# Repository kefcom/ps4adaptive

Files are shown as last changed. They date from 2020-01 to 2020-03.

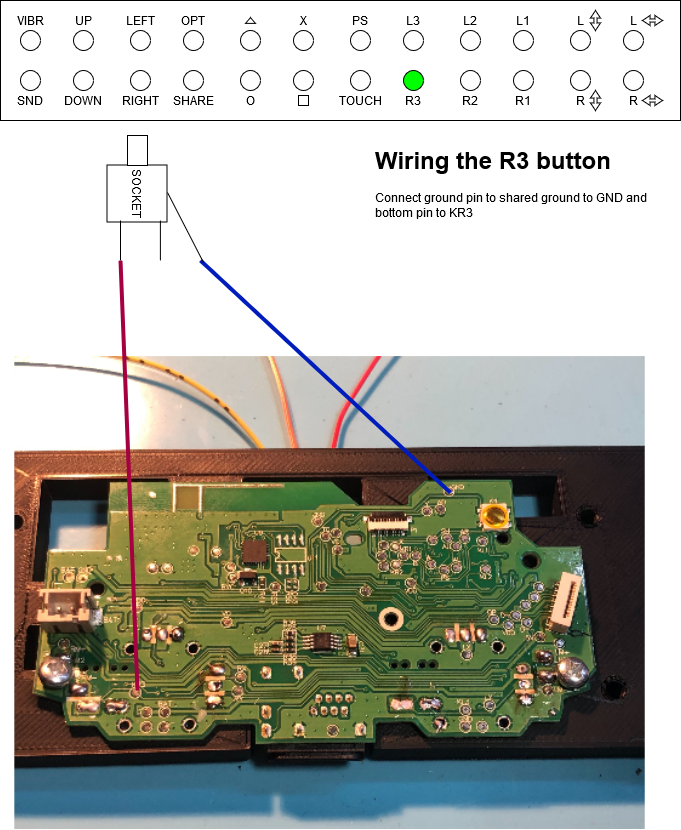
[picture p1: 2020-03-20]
controller/controller c1931/images/Schematic_R3.png

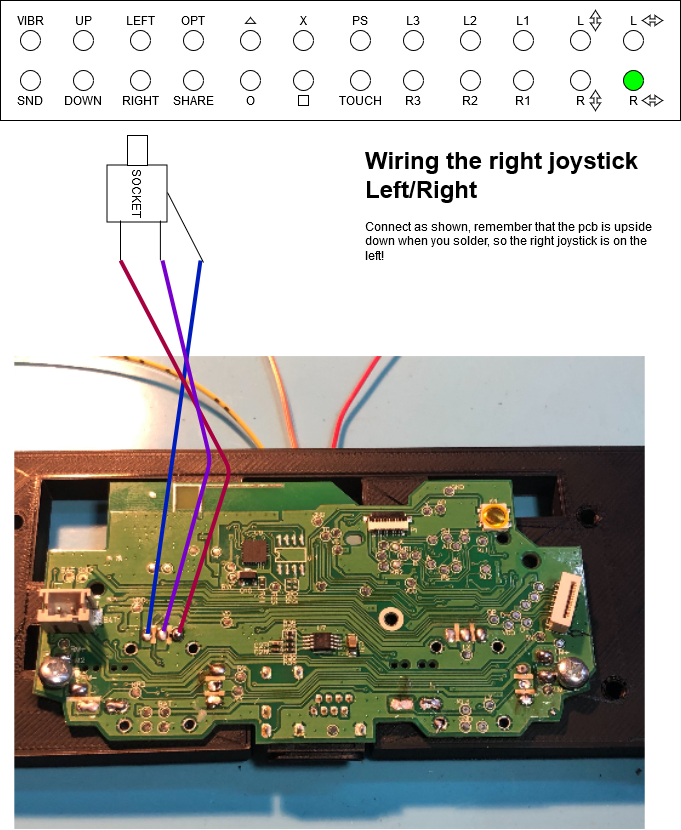
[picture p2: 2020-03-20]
controller/controller c1931/images/Schematic_Joystick_right_leftright.png

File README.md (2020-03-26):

# ps4adaptive

Welcome to the home of the ps4 adaptive controller github repository.
Here you can find every file to create your own controller and modules.

## Current version: 0.1 beta
## Supported PCB modelnumbers: 191105-v11, C1931

To get you started: Use the controller identifier document to figure out what type of pcb is in your controller, then go to the 'controller' folder and open the folder with that pcb version number.
Here you can find instructions, source files and a bill of materials.

I'm looking for support on this project! If you want to help out, shoot me a message! Designing better buttons would help out a lot, as wel as mapping out new pcb versions as they appear on the market.

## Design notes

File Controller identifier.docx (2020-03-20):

# Controller identifier

Look at the back of your controller, if it looks like the image shown, use the pcb version number to get instructions on how to wire your controller.

If you can’t find your device, download the all the controller instructions and see if the pcb looks familiar.

Remember: official sony ps4 controllers are NOT supported! They don’t provide pads to solder wires to.

# 191105-v11

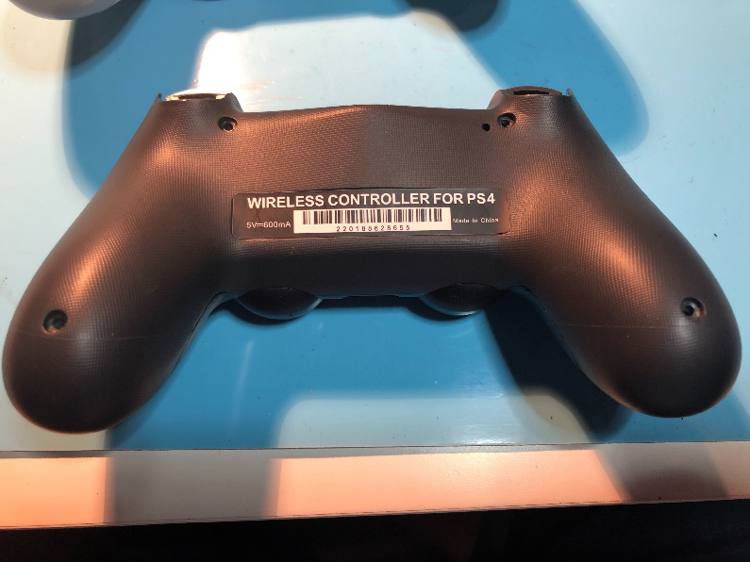
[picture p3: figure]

# C1931

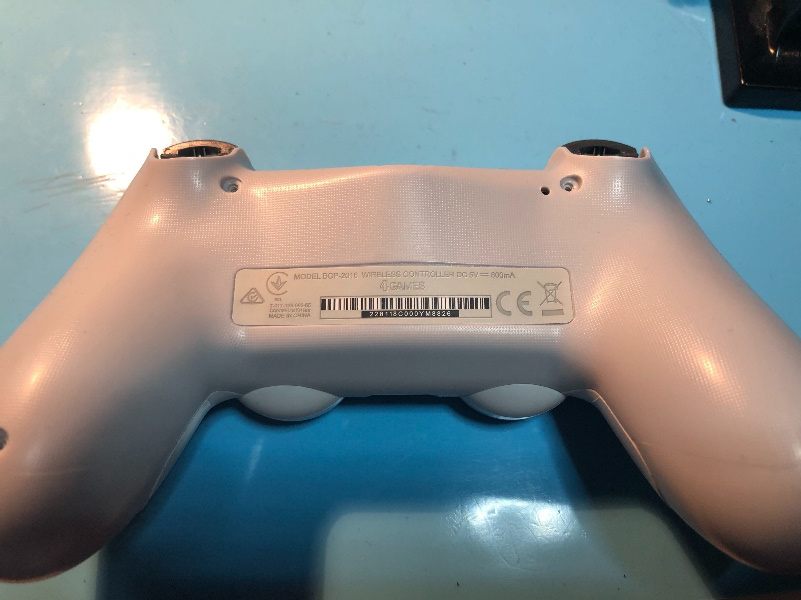
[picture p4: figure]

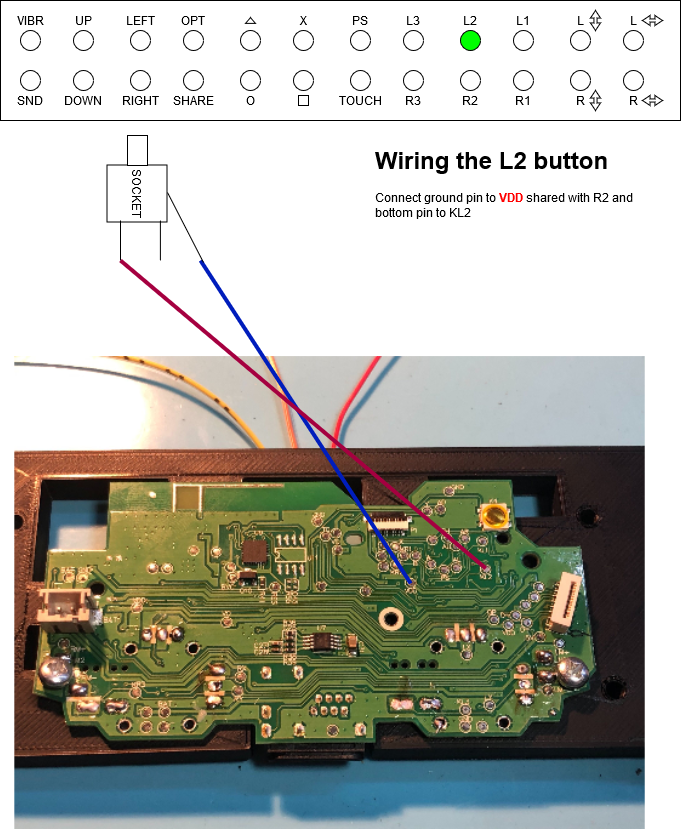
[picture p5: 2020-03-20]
controller/controller c1931/images/Schematic_L2.png

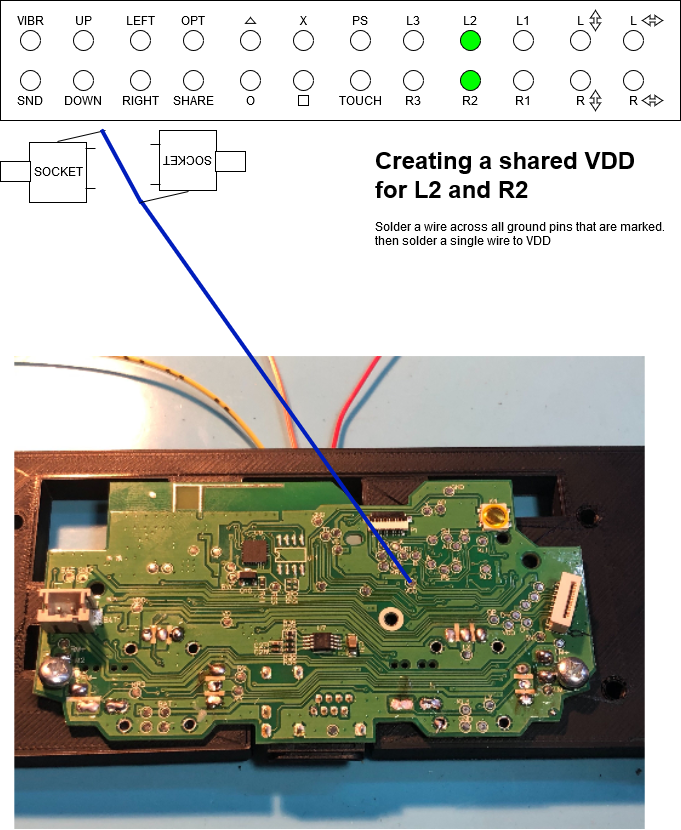
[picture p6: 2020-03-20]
controller/controller c1931/images/Schematic_sharedVCC.png

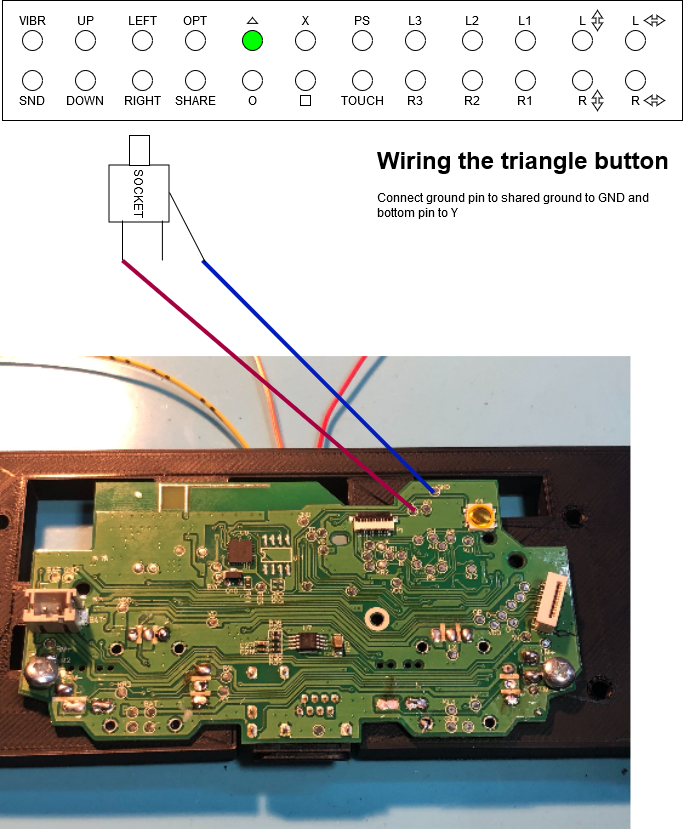
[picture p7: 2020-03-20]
controller/controller c1931/images/Schematic_triangle.png

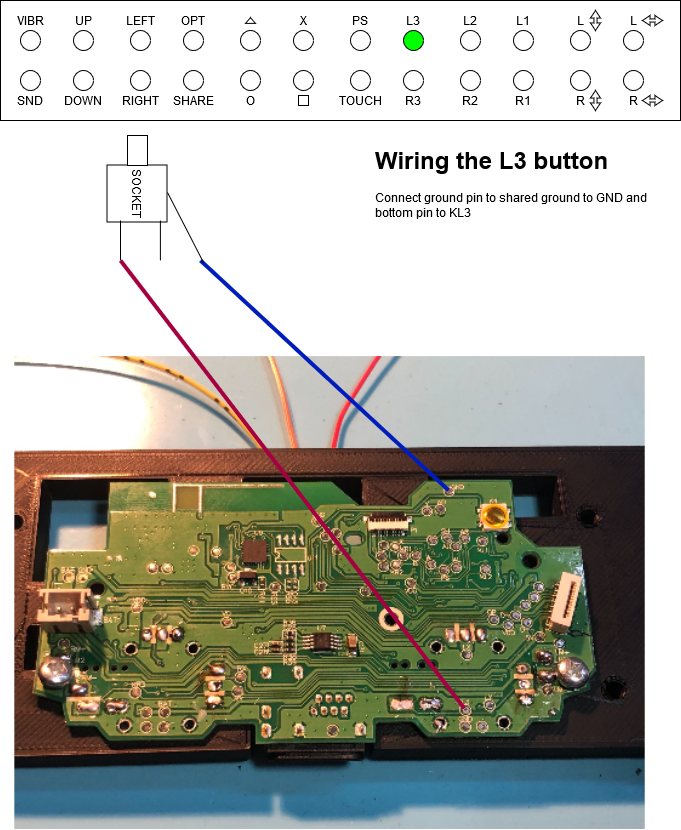
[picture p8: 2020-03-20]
controller/controller c1931/images/Schematic_L3.png

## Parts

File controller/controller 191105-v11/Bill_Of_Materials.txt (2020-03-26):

PS4 Adaptive controller
Bill of materials:

1x project case:
	Description: Plastic Electronic Project Box Enclosure Instrument Shell Case DIY 130x170x55MM Wholesale&DropShip
	Price (can change over time): €3,63
	Link: https://s.click.aliexpress.com/e/_dZoKXoF

1x Lasercut or 3D printed front plate
	Description: Front plate to hold the sockets
	Price (can change over time): /
	Link: you can find the models in the 'models' folder.

1x Lasercut or 3D printed back plate
	Description: Back plate for the controller
	Price (can change over time): /
	Link: you can find the models in the 'models' folder.

1x 3D printed PCB holder
	Description: A 3D print to hold the pcb
	Price (can change over time): /
	Link: you can find the models in the 'models' folder.

1x PS4 compatible controller
	Description: A wireless PS4 compatible controller
	Price (can change over time): ~18€
	Link: https://s.click.aliexpress.com/e/_dY3XY7H 

24x 3.5mm Stereo audio jacks
	Description: Stereo audio jacks (mono jacks work for buttons, but not for the speaker and the joysticks, so make sure they are stereo!)
	Price (can change over time): ~0.91€ / 10pcs
	Link: https://s.click.aliexpress.com/e/_dVuoD62

51 Wires
	Description: Wire to solder the pcb to the sockets. I prefer rainbow wire
	Price (can change over time): 2.72€
	Link: https://www.aliexpress.com/item/802052578.html

22x Audio cables
	Description: Standard stereo audio cabled to connect modules to the controller
	Price (can change over time): 0.7€ / 1m
	Link: https://s.click.aliexpress.com/e/_dTZJgun 	

4x Screws
	Description: Diameter: 2.9 x 9.5mm
	Price: €2.39 / 40pcs
	Link: No link, check local hardware store.

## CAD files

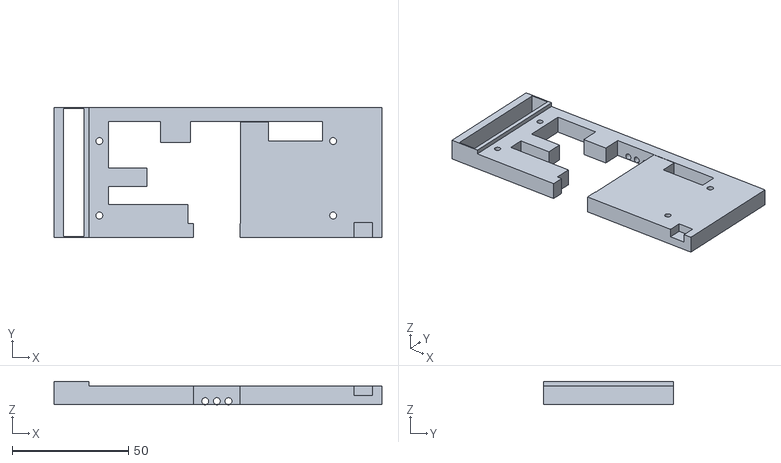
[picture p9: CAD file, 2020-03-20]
controller/controller c1931/models/3D print/pcb holder c1931.stl
141.0 x 56.0 x 10.0

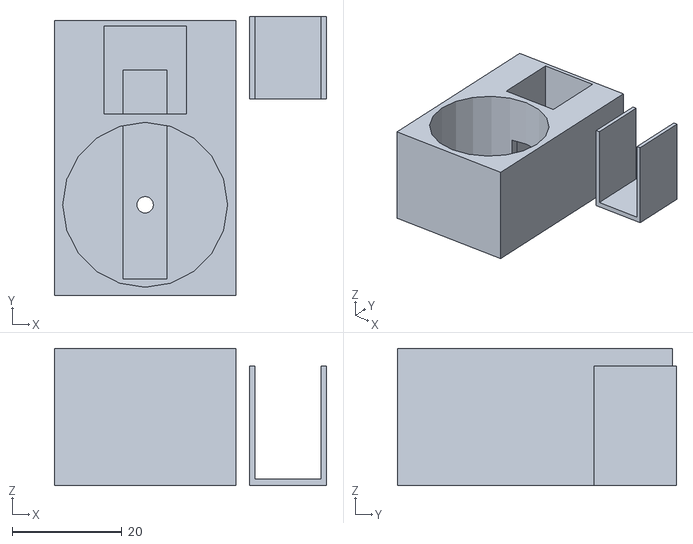
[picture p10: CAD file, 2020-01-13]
modules/1x arcadebutton/arcadebutton.stl
49.5 x 50.8 x 25.0

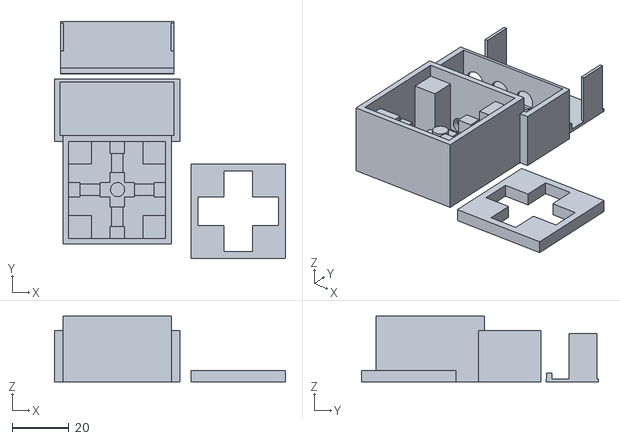
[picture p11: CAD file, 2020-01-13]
modules/1x d-pad/D-pad.stl
81.1 x 83.3 x 23.0

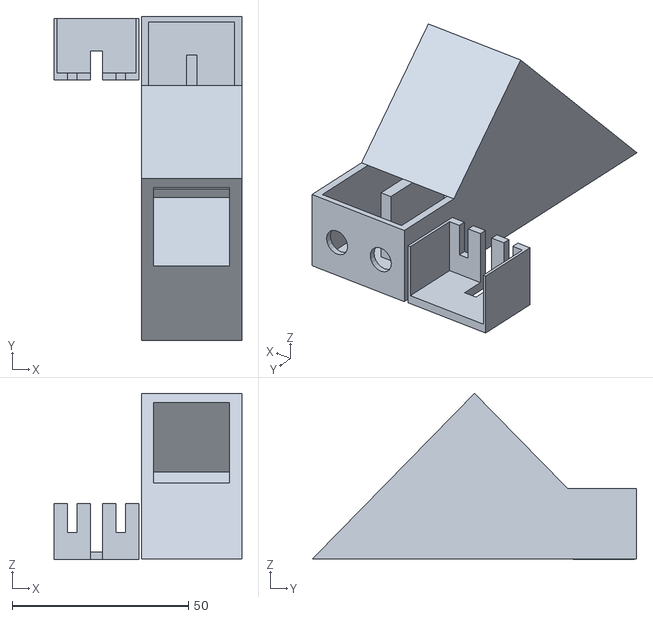
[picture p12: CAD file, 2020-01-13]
modules/1x rockerswitch on-off-on/1xon_off_on rocker switch.stl
53.2 x 92.0 x 47.2

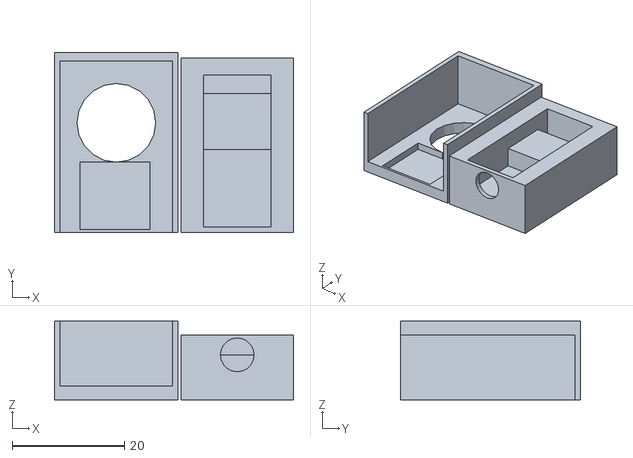
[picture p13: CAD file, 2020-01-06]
modules/1x simple button with tactile feedback/3D model.stl
42.5 x 32.0 x 14.0

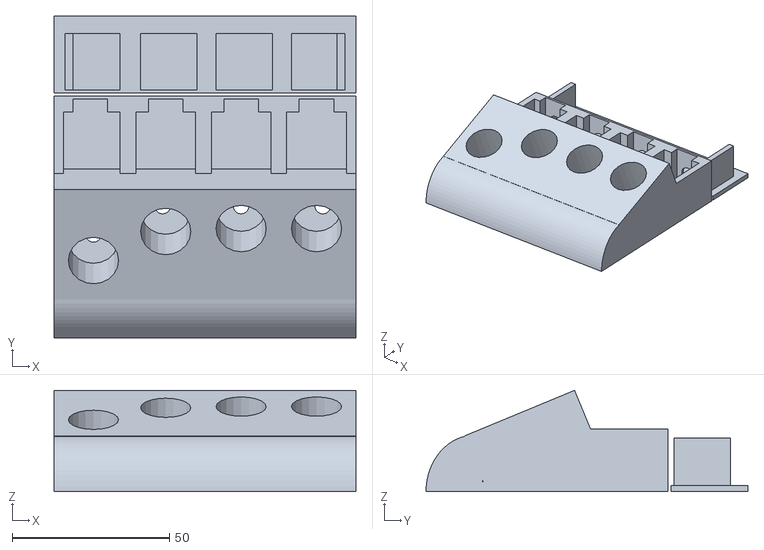
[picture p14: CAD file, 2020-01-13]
modules/4x button/4x pushbutton.stl
96.0 x 102.5 x 32.2

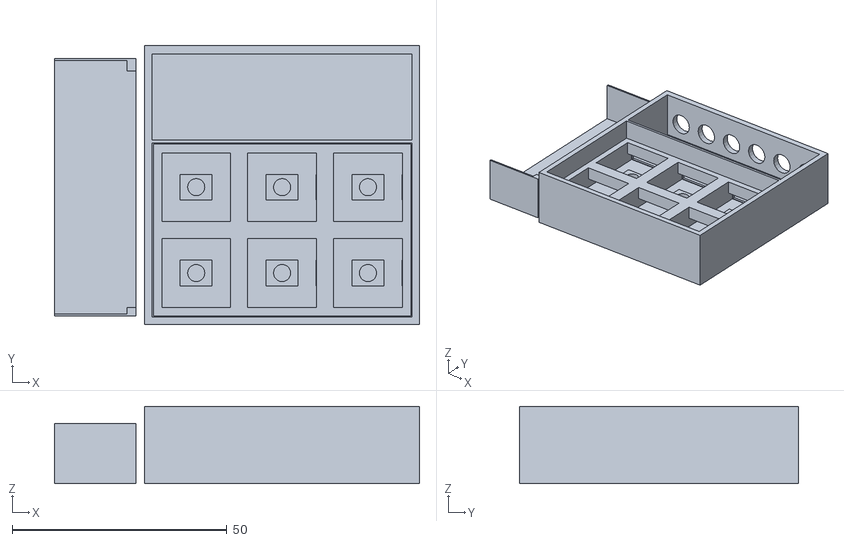
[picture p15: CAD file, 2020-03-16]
modules/6x keyboard/6x keyboard.stl
85.0 x 65.0 x 18.0

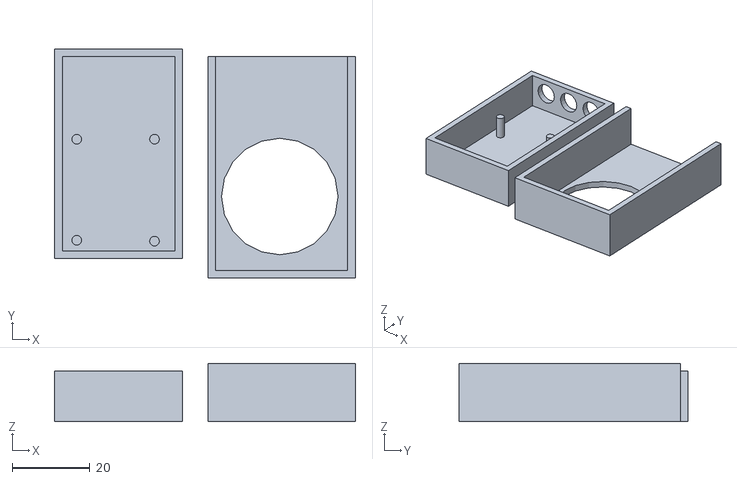
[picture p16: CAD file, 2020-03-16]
modules/joystick with click/joystick with click.stl
77.5 x 59.0 x 15.0

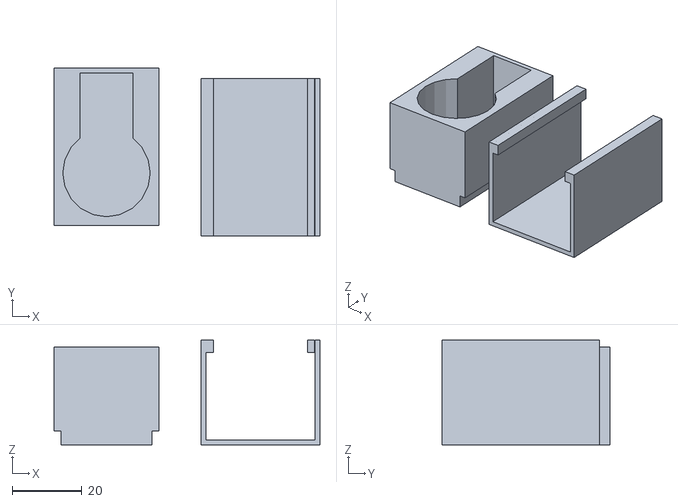
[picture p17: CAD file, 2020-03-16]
modules/vibrator/vibrator.stl
76.0 x 48.0 x 30.0

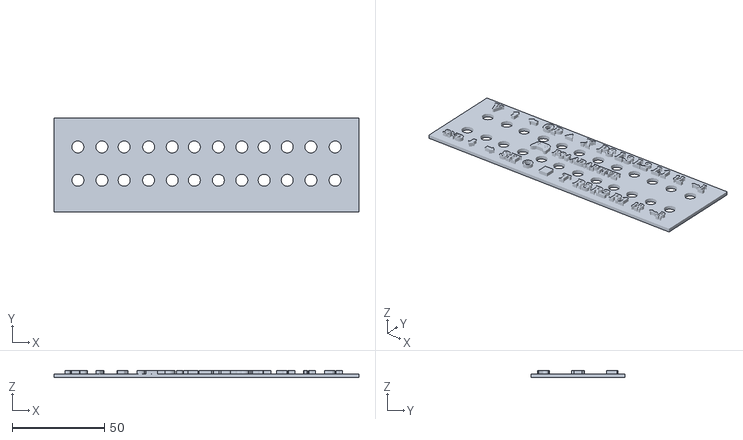
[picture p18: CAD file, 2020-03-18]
controller/controller c1931/models/3D print/ps4 adaptive frontplate.stl
165.0 x 51.0 x 4.00

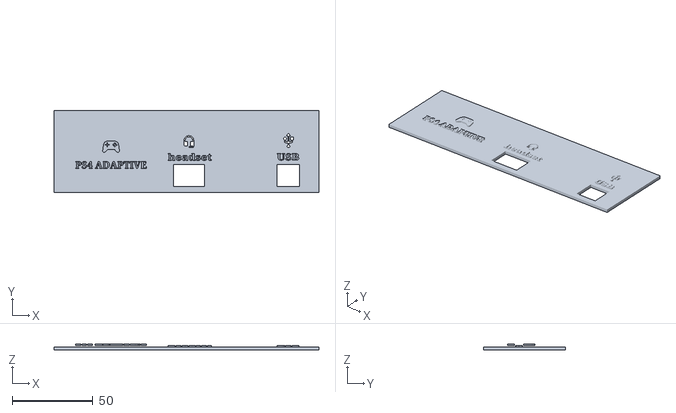
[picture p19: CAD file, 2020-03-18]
controller/controller c1931/models/3D print/ps4 adaptive backplate.stl
163.8 x 50.8 x 4.00

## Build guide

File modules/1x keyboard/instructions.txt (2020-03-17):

Instructions:

Print the model
cut and strip 2 wires
pre-solder socket (top and bottom pin)
pre-solder wires
pre-solder pins on keyboard switch
solder wires to keyboard switch
thread wires trough holes in the print to where the socket goes
solder wire to socket and tighten
test
place keycaps
place a strip of hot glue on top of socket and on the side of the cover plate, then secure cover plate
glue velcro strip to bottom

done

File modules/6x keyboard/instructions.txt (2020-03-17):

Instructions:

Print the model
cut wire: 
- 6 wires to cover row 1 to the sockets
- 6 wires to cover row 2 to the sockets
strip wire ends
pre-solder sockets (top and bottom pin)
pre-solder wires
pre-solder pins on keyboard switches
solder wires to keyboard switches
thread wires trough holes in the print to where the sockets go (alternate a long one (second row) first, then a short one (first row))
solder wire to socket and tighten
repeat for all switches
test
place keycaps
place a strip of hot glue on top of sockets and secure cover plate
glue velcro strips to bottom

done

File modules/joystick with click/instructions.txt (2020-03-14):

Instructions:

Print the model
cut wire: 
- 1 to strech over the 3 sockets to ground (strip completely)
- 1 to stretch over 2 sockets to +5v (strip completely)
- and 3 small wires to the other pins (strip ends)
pre-solder wires
pre-solder sockets (all 3 pins)
pre-solder pins on joystick
solder wire accross top pins of the three sockets
solder wire accross bottom pins of two of the sockets
solder top wire to gnd
solder bottom wire to +5v
solder bottom pin of remaining socket to sw
solder mid pins of the two other sockets to VRx and VRy
fit sockets into holes
test fit the joystick module (you might need to bend some pins) make sure the pins are not touching each other!
remove joystick module and place some hotglue under it, then place it back
let glue dry
lock sockets in place with nuts
test fit top part of the 3D print
place joystick cap and test if you can move in all directions
if all good: hotglue the sides, put top part in place
let glue dry
hotglue some velcro to bottom

done

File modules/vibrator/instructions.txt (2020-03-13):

Instructions:

Print the model
pre-solder the socket
solder motor wires to the socket (top and bottom pin, order should not be important)
fit socket in the model
secure socket with nut
place motor in the model
hotglue sided of the model
slide the other part of the model to close it
done.

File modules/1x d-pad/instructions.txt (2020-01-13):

instructions:

cut button pins to length (about half of the original size)
pre-solder button pins
pre-solder wires
pre-solder sockets

solder wires to buttons
thread wires as shown in the video and place buttons

solder wires to sockets

place sockets

test (if possible)

place coverplate

place flexpad on the buttons
place d-pad rocker and topcover

if it all fits nice, glue the topcover in the corners and stick it on the design.

glue velcro strips

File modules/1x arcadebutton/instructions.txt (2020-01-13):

Instrucions:

Strip wires
Pre-solder wires
Pre-solder button pins
Pre-solder socket

Solder wires to button pins
Bend button pins flat
Place button and thread wire
(button needs to be flat to top of print)
Solder wires to socket
Place socket and tighten locknut

place cover

test (if possible)

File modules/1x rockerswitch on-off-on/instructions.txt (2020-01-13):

instructions:

strip wires
pre-solder wires
pre-solder rocker switch
pre-solder sockets

solder wires to rocker switch (2 wires to the middle terminal, one to the upper and bottom one)
place switch and thread wires (1 from the middle + 1 from the top or bottom) to each side
solder wires to the sockets (the wire from the middle goes to the ground pin (the one on the outside))
place sockets and tighten

place cover.

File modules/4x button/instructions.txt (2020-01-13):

Instructions:

Pre-solder the button terminals
Pre-solder the socket terminals and bend the ground pin down and the middle pin inwards.
measure and cut 8 wires to length, some extra is no problem.
strip wires
pre-solder wires (both ends) and solder them to the buttons
slide in buttons and makre sure wire is long enough
press down button (tight fit) (if button placement is wrong, you can press the buttons up from holes on the bottom of the 3D print)
solder wires to sockets
test (if possible)
close print
hot glue strips of velcro.

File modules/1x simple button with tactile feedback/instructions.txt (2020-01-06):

Begin by bending the ground pin on the socket inward.
This is the pin that sticks out on the side of the socket.

Now apply some solder to the ground pin and the left audio channel pin.
The left audio channel pin is on the other side of the socket.

Test fit the button to check if it fits. Remove the button again and
apply some solder to two pins on the same side of the button.

Strip 2 wires and apply some solder to them.
Solder the wires to the button.

Now measure how long the wire needs to be between the socket and the button.
Beware that there is not much space for extra wire.

Cut the wires and strip them.
Apply some solder and solder the wires to the socket.

Now bend the left and right audio channel pins inward
(or better, cut the right audio channel pin as we don't need it).

Place the socket in the model making sure the socket is in the hole on the front.
place it as far forward as it goes.

Place the button. Make sure it's pins are not touching the socket's pins.

If you have a tester, you can now test the button and fix issues.

Place top cover and snap everything in place.

Place button cap.

Take a piece of velcro and hotglue it to the bottom making sure
the 'hook' side (the rough side) is facing down. The soft part should be touching
the button model.

Wait for it to cool and remove any excess glue if needed.

The button should be finished now.

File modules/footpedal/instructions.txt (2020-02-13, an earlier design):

Instructions:

unpack the pedal
unscrew screw at the bottom
remove locking pin by holdin the pedal pressed down and pushing against the pin.
unscrew wire clamp
unscrew 2 screws holding the button in place
desolder existing wires
pre-solder new wires
pre-solder 3.5mm socket
remove or bend middle pin from 3.5mm socket, we will not be using it
solder wires from ground to ground and from NC to the remaining pin on the 3.5mm socket
place 3.5mm socket in the pedal
place button in original position and fasten screws
now hold the 3.5mm socket in place and pour hotglue down the sides. Be carefull not to get glue in the back of the socket as it will stop the socket from working properly.
let it dry enough to stay in place
pour a little bit of hot glue in the top part of the pedal where the spring sits
glue spring in place on the top part
place top part back onto the bottom part and insert locking pin
screw down bottom screw
test

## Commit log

2020-01-06 Added "1x simple button with tactile feedback" to modules.
    [3D model.stl]
2020-01-13 added 4x button module
    [4x pushbutton.stl]
2020-01-13 forgot rockerswitch stl design
    [1xon_off_on rocker switch.stl]
2020-01-13 added arcadebutton module
    [arcadebutton.stl]
2020-01-13 added d-pad module fixed arcadebutton requirements.txt
    [D-pad.stl]
2020-01-15 Added image to simple button module
2020-01-15 Added image to 4x button module
2020-03-16 added 6x keyboard module. - added missing stl files for vibrator module and joystick with click module.
    [6x keyboard.stl, joystick with click.stl, vibrator.stl]
2020-03-18 Added the main module. The project is now in beta :)
    [pcb holder.stl, ps4 adaptive backplate.stl, ps4 adaptive frontplate.stl]
2020-03-20 updated schematics to fix mistake
2020-03-20 added controller model c1931 instructions introduced controller identifier document
    [pcb holder.stl, ps4 adaptive backplate.stl, ps4 adaptive frontplate.stl]
2020-03-20 updated pcb holder for c1931 controller to fit battery
    [pcb holder c1931.stl, pcb holder.stl]
2020-03-26 changed link for 3.5mm jacks. fixed typo
